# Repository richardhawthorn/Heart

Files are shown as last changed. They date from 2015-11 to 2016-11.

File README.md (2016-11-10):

### Description

LED Heart

<div id="link">
	<a href="http://www.deluxecapacitor.com/projects/view/16">Project Page</a>
</div>

### Features

- 20 LED display
- Charlieplex LED control
- Built in microphone and amplifier
- ATTINY44 processor
- 3V operation @ 1Mhz or 8Mhz
- 1x button
- ICSP port
- Holes for necklace chain

### License

This work is licensed under a Creative Commons Attribution-ShareAlike 4.0 International License.

<br />
Designed by <a xmlns:cc="http://creativecommons.org/ns#" href="http://www.richardhawthorn.com" property="cc:attributionName" rel="cc:attributionURL" target="_blank">Richard Hawthorn</a><br />
<a rel="license" href="http://creativecommons.org/licenses/by-sa/4.0/" target="_blank">View License</a>

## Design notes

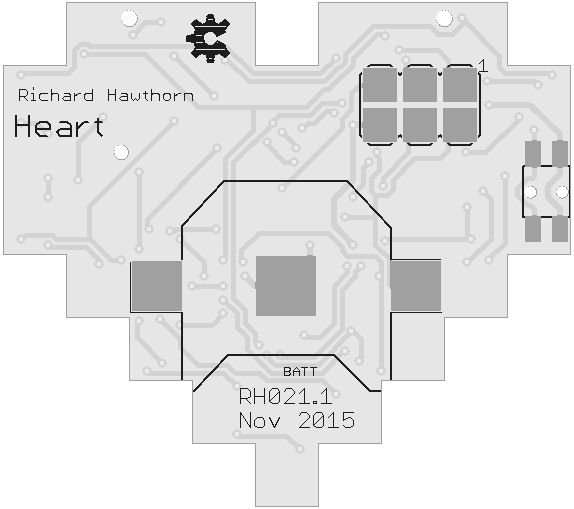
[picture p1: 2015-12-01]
images/pcb_front.png

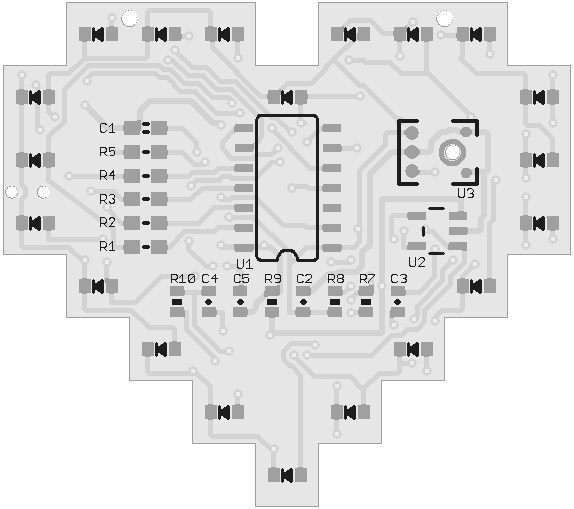
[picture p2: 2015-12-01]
images/pcb_back.png

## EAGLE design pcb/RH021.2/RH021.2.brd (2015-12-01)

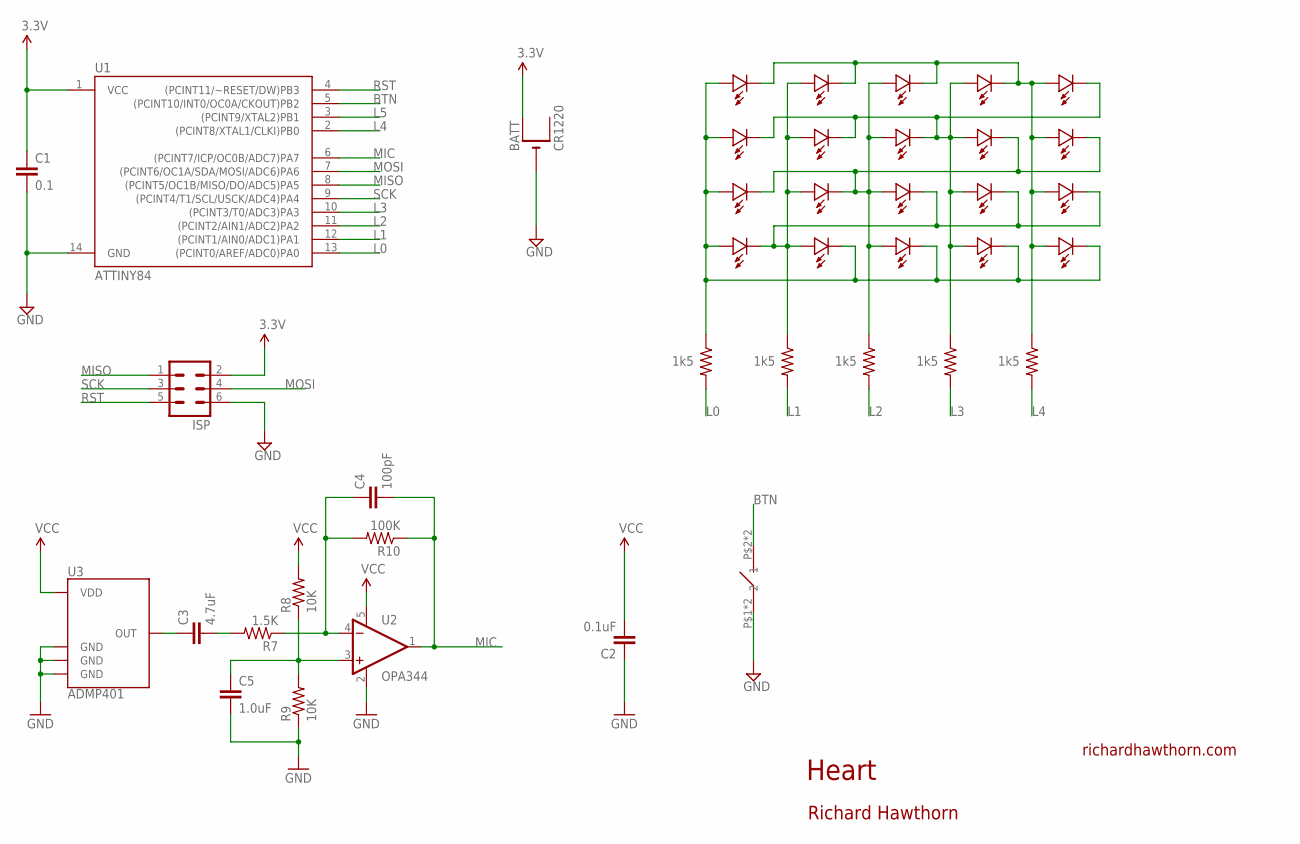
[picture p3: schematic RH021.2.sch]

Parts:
BATT: CR1220; CR1220-SMD
BTN1: TURTLE-3PIN
C1: 0.1; 0603-CAP
C2: 0.1uF; 0402-CAP
C3: 4.7uF; 0402-CAP
C4: 100pF; 0402-CAP
C5: 1.0uF; 0402-CAP
ISP: MA03-2
LED1, LED2, LED3, LED4, LED5, LED6, LED7, LED8, LED9, LED10, LED11, LED12, LED13, LED14, LED15, LED16, LED17, LED18, LED19, LED20: LED0603; 0603-LED
R1, R2, R3, R4, R5: 1k5; 0603-RES
R7: 1.5K; 0402-RES
R8, R9: 10K; 0402-RES
R10: 100K; 0402-RES
U1: ATTINY84; SO14
U2: OPA344; SOT23-5
U3: ADMP401

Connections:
BTN: BTN1.P$2 (2), BTN1.P$4 (2), U1.5 ((PCINT10/INT0/OC0A/CKOUT)PB2)
C7N$1: C3.1, U3.1 (OUT)
GND: BATT.-, BTN1.P$1 (1), BTN1.P$3 (1), C1.2, C2.1, C5.2, ISP.6, R9.1, U1.14 (GND), U2.2 (V-), U3.2 (GND), U3.4 (GND), U3.6 (GND)
L0: R1.2, U1.13 ((PCINT0/AREF/ADC0)PA0)
L1: R2.2, U1.12 ((PCINT1/AIN0/ADC1)PA1)
L2: R3.2, U1.11 ((PCINT2/AIN1/ADC2)PA2)
L3: R4.2, U1.10 ((PCINT3/T0/ADC3)PA3)
L4: R5.2, U1.2 ((PCINT8/XTAL1/CLKI)PB0)
L5: U1.3 ((PCINT9/XTAL2)PB1)
MIC: C4.2, R10.1, U1.6 ((PCINT7/ICP/OC0B/ADC7)PA7), U2.1 (OUT)
MISO: ISP.1, U1.8 ((PCINT5/OC1B/MISO/DO/ADC5)PA5)
MOSI: ISP.4, U1.7 ((PCINT6/OC1A/SDA/MOSI/ADC6)PA6)
unnamed: C4.1, R7.1, R10.2, U2.4 (-IN)
unnamed: C3.2, R7.2
unnamed: C5.1, R8.1, R9.2, U2.3 (+IN)
unnamed: LED2.PLUS, LED7.PLUS, LED12.PLUS, LED13.MINUS, LED14.MINUS, LED15.MINUS, LED16.MINUS, LED17.PLUS, R2.1
unnamed: LED1.PLUS, LED6.PLUS, LED11.PLUS, LED16.PLUS, LED17.MINUS, LED18.MINUS, LED19.MINUS, LED20.MINUS, R1.1
unnamed: LED1.MINUS, LED2.MINUS, LED3.MINUS, LED4.MINUS, LED5.PLUS, LED10.PLUS, LED15.PLUS, LED20.PLUS, R5.1
unnamed: LED4.PLUS, LED5.MINUS, LED6.MINUS, LED7.MINUS, LED8.MINUS, LED9.PLUS, LED14.PLUS, LED19.PLUS, R4.1
unnamed: LED3.PLUS, LED8.PLUS, LED9.MINUS, LED10.MINUS, LED11.MINUS, LED12.MINUS, LED13.PLUS, LED18.PLUS, R3.1
RST: ISP.5, U1.4 ((PCINT11/~RESET/DW)PB3)
SCK: ISP.3, U1.9 ((PCINT4/T1/SCL/USCK/ADC4)PA4)
VCC: BATT.+$1 (+), C1.1, C2.2, ISP.2, R8.2, U1.1 (VCC), U2.5 (V+), U3.5 (VDD)

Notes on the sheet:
Heart
richardhawthorn.com
Richard Hawthorn

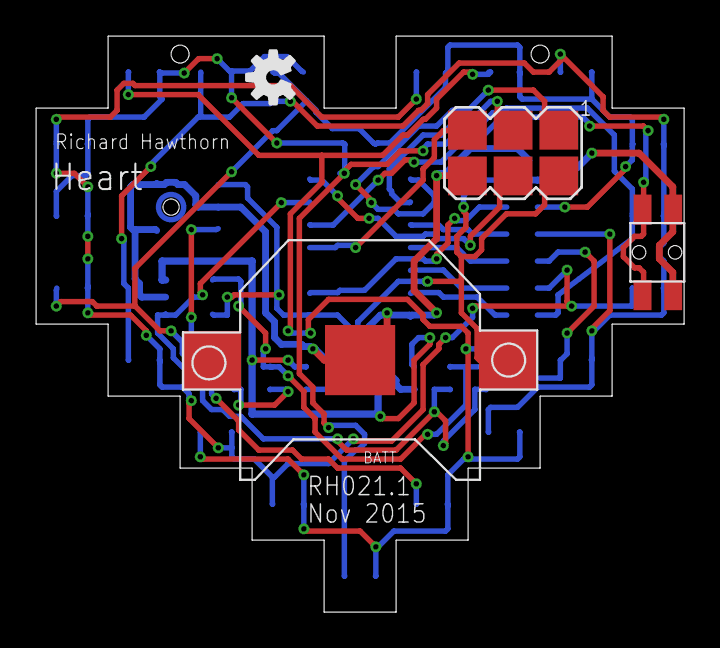
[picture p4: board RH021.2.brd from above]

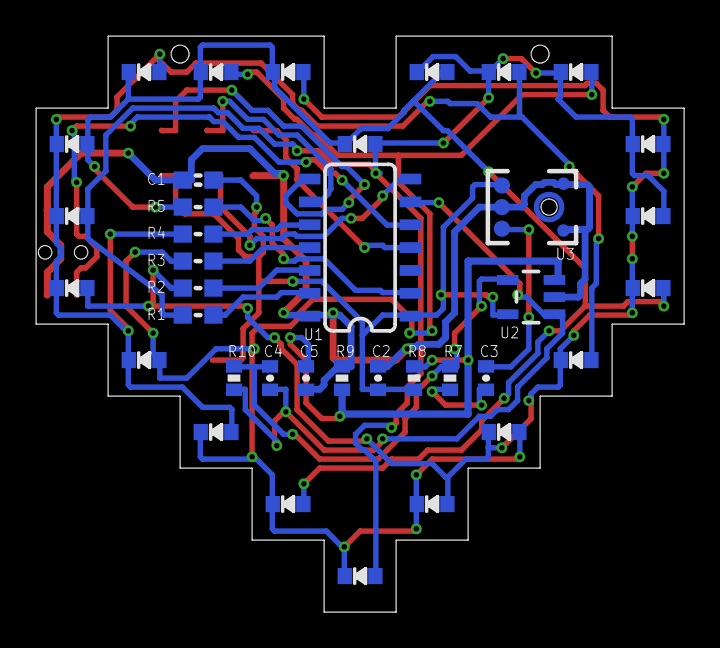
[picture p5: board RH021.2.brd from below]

Board: 2 copper layers, 36.0 x 32.0 mm, 41 parts (37 on the bottom side), 22 nets.

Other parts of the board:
U$3: OSHW-LOGO-S

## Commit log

2015-11-10 first version of the pcb
    [RH021.1.brd, RH021.1.sch]
2015-11-10 updated labels
    [RH021.1.brd]
2015-11-10 added gerbers
2015-11-11 swap 2 leds
    [RH021.1.brd]
2015-12-01 Updated to more satisfying shape
    [RH021.2.brd, RH021.2.sch]

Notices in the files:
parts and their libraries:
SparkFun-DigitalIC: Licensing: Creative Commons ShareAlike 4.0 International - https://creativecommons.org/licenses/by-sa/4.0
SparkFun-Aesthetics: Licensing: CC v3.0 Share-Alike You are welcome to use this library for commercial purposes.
